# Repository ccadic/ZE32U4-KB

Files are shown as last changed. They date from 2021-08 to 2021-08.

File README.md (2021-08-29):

# ZE32U4-KB
12 low profile keys USB Keyboard with OLED, an ATMega32U4
Dr CADIC Philippe pcadic@gmail.com
GPL 3

This directory also has solidworks files for 3D files

The KAILH low profile are purchasable here: https://fr.aliexpress.com/item/32989908397.html?spm=a2g0s.9042311.0.0.27426c37iG4w2C
The Arduino like ATMEGA is a PRO MICRO : https://www.amazon.com/OSOYOO-ATmega32U4-arduino-Leonardo-ATmega328/dp/B012FOV17O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
The OLED is an I2C SSD1336: https://www.amazon.com/Pieces-Display-Module-SSD1306-3-3V-5V/dp/B08CDN5PSJ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

Size: 70x80

You have a demo software for aduino in the appropriate subdirectory.

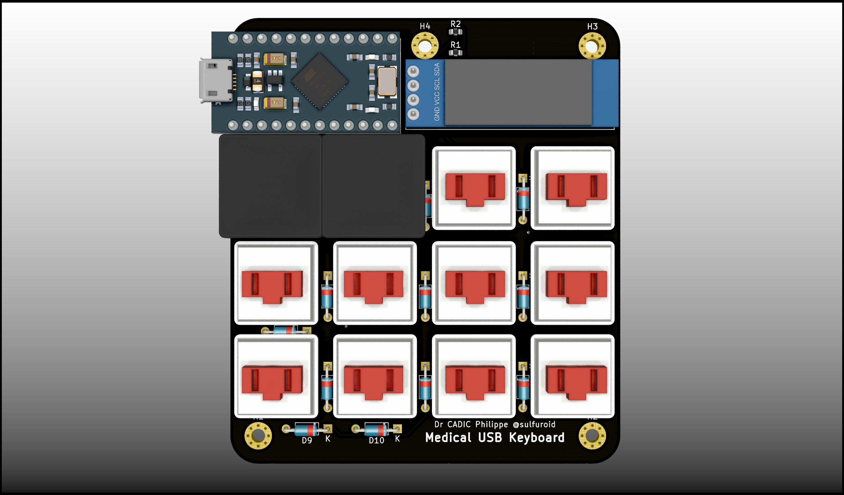
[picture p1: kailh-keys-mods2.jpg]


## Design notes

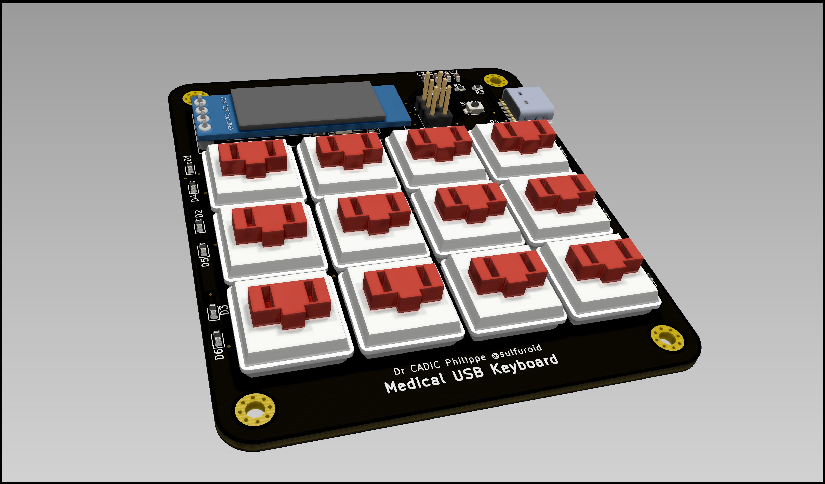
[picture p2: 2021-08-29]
kailh-keys5.jpg

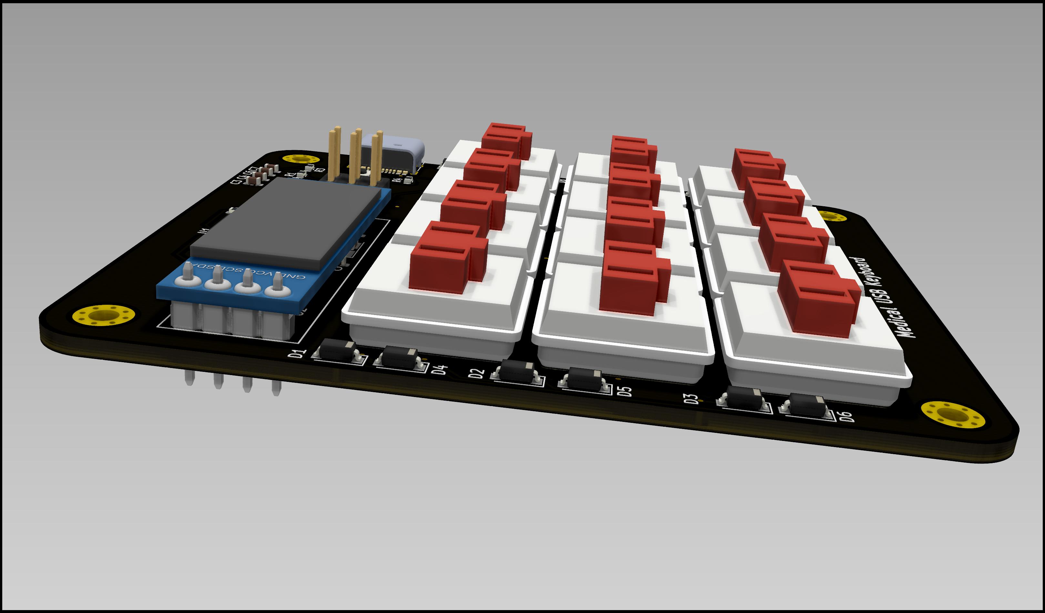
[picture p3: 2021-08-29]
kailh-keys4.jpg

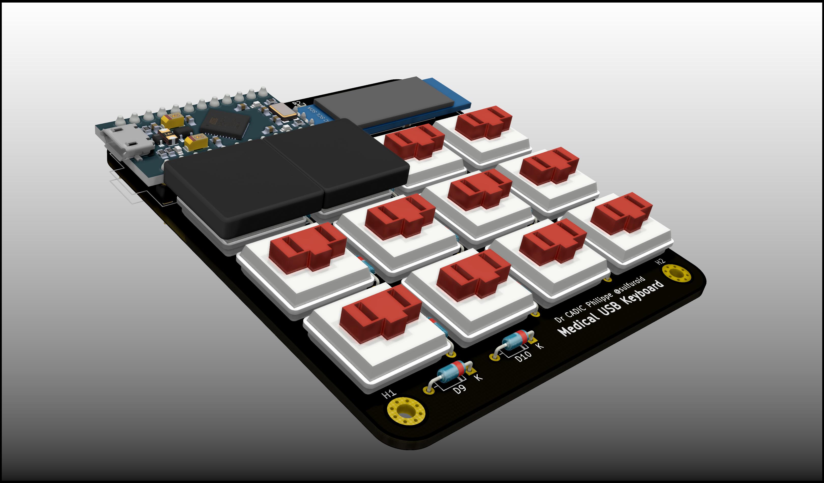
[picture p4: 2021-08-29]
kailh-keys-mods.jpg

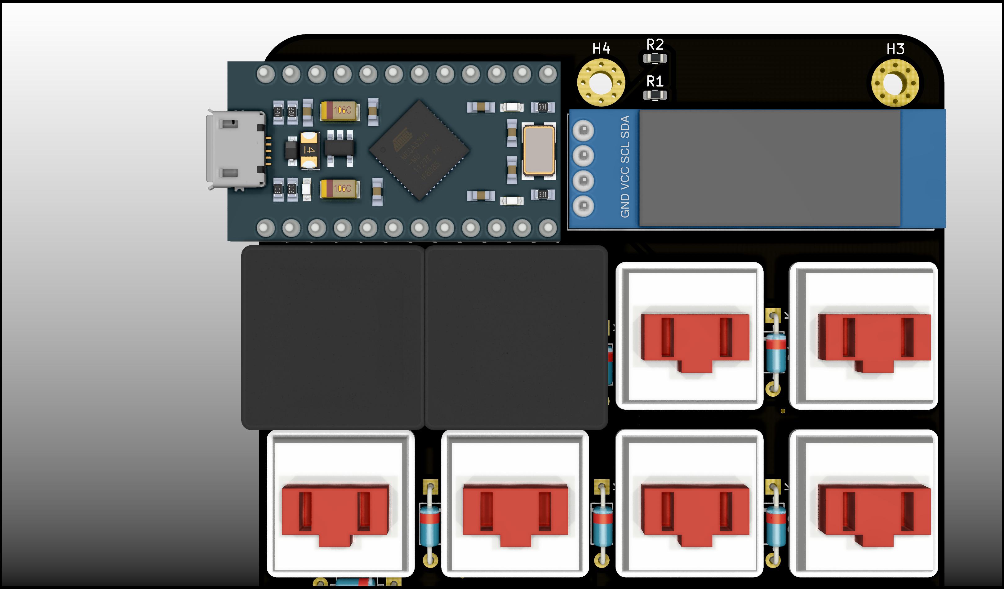
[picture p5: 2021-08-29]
kailh-keys-mods3.jpg

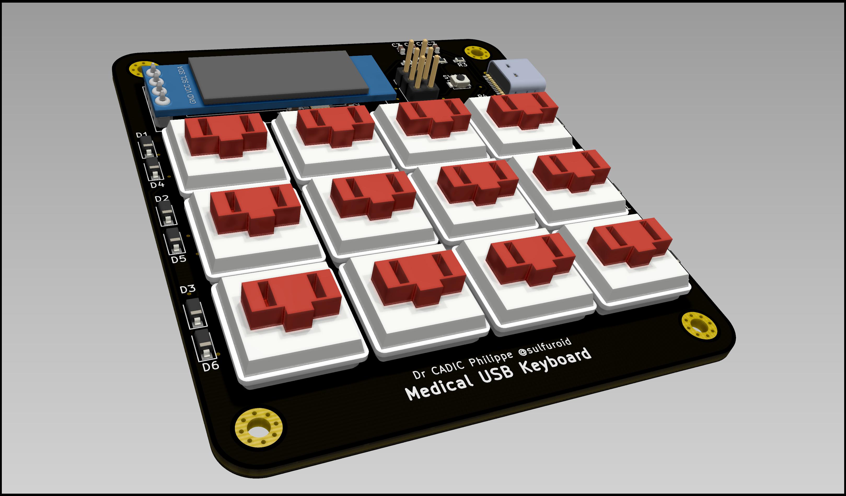
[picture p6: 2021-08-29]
kailh-keys2.jpg

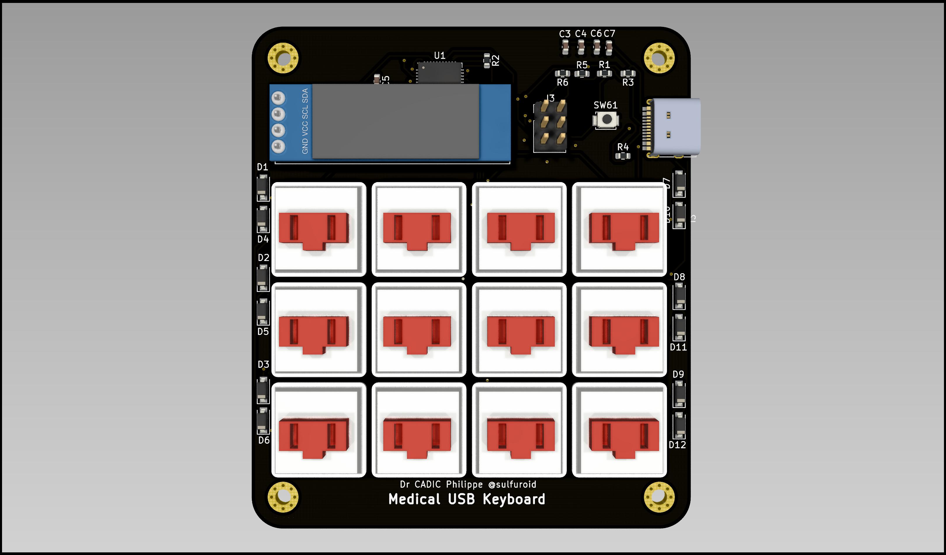
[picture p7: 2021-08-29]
kailh-keys.jpg

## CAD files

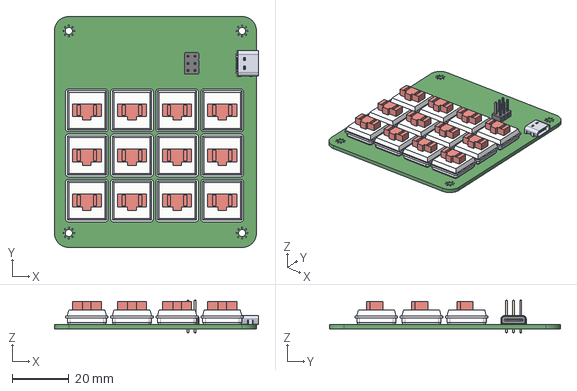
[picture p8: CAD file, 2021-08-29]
kailh-keys - 3Dprint.step
71.9 x 81.3 x 11.5 mm

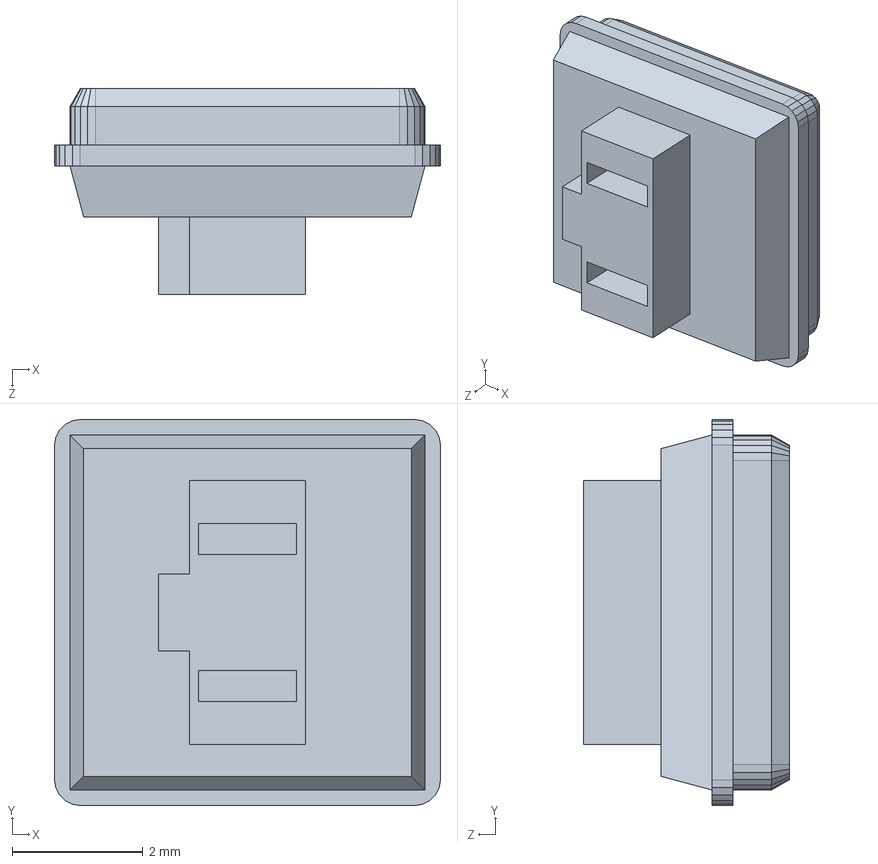
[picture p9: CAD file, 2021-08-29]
shapes3D/kailh choclp.wrl.SLDPRT
5.91 x 5.91 x 3.15 mm

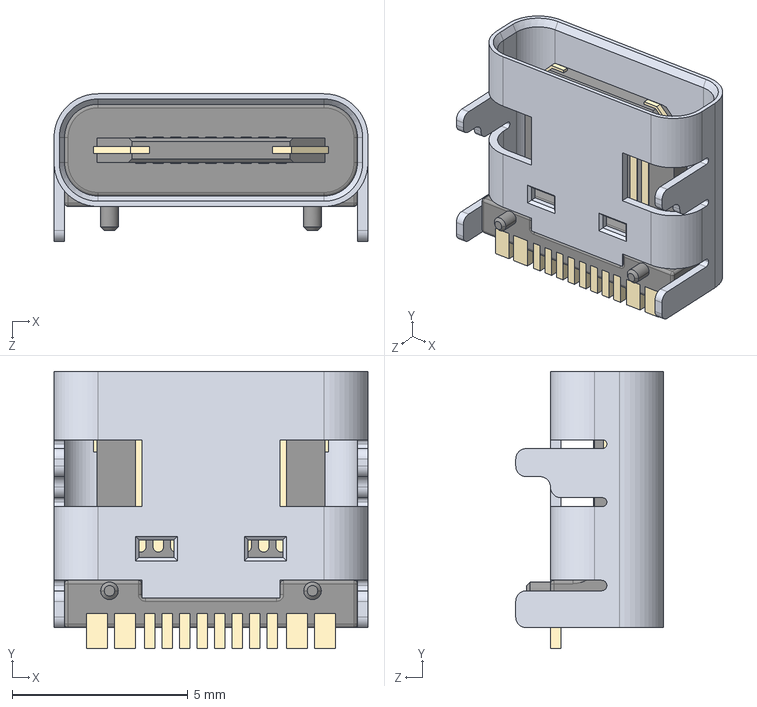
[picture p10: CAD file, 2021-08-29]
USB Type C Port (SMD Type).STEP
8.94 x 7.90 x 4.20 mm

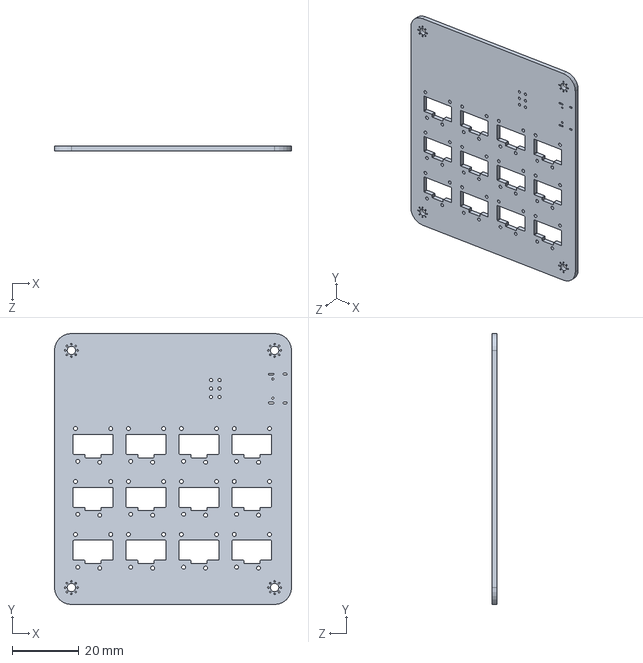
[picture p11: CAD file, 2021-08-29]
Pièce3.SLDPRT
71.1 x 81.3 x 1.60 mm

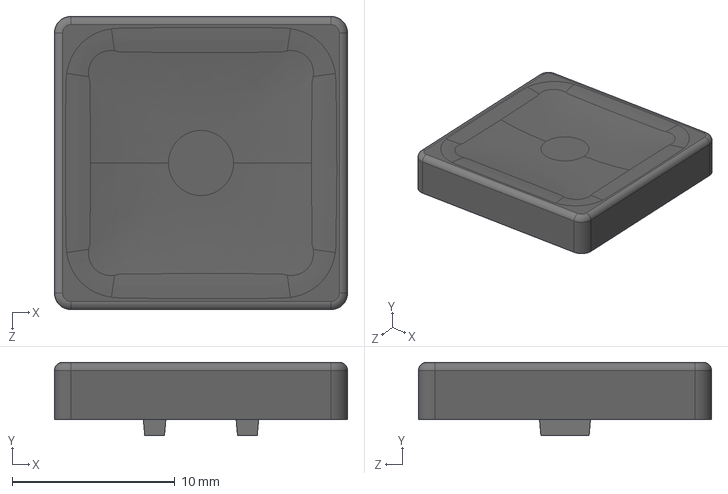
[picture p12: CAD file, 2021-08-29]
choc.STEP
18.0 x 4.50 x 18.0 mm

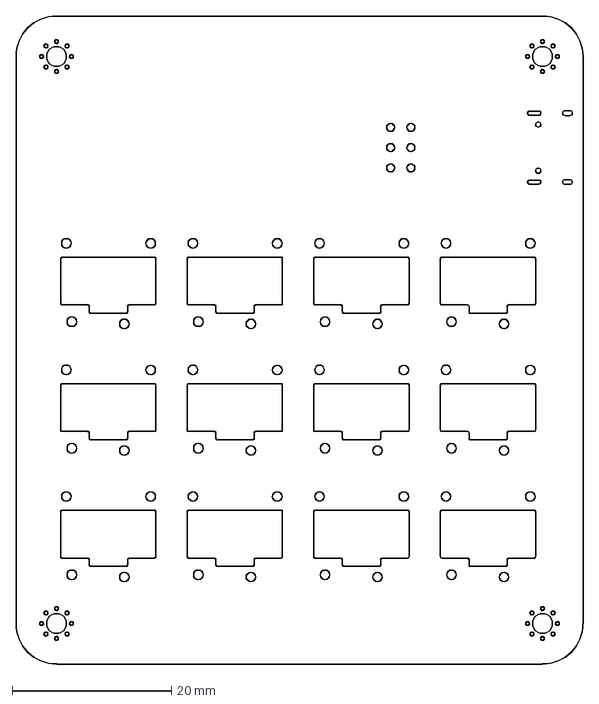
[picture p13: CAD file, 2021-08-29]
miniclavier3.DXF
71.1 x 81.3 mm

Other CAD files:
kailh-keys - 3Dprint45.step
kailh-keys - 3Dprint.STL
kailh-keys - 3Dprint45.SLDASM
kailh-keys - 3Dprint45.SLDPRT

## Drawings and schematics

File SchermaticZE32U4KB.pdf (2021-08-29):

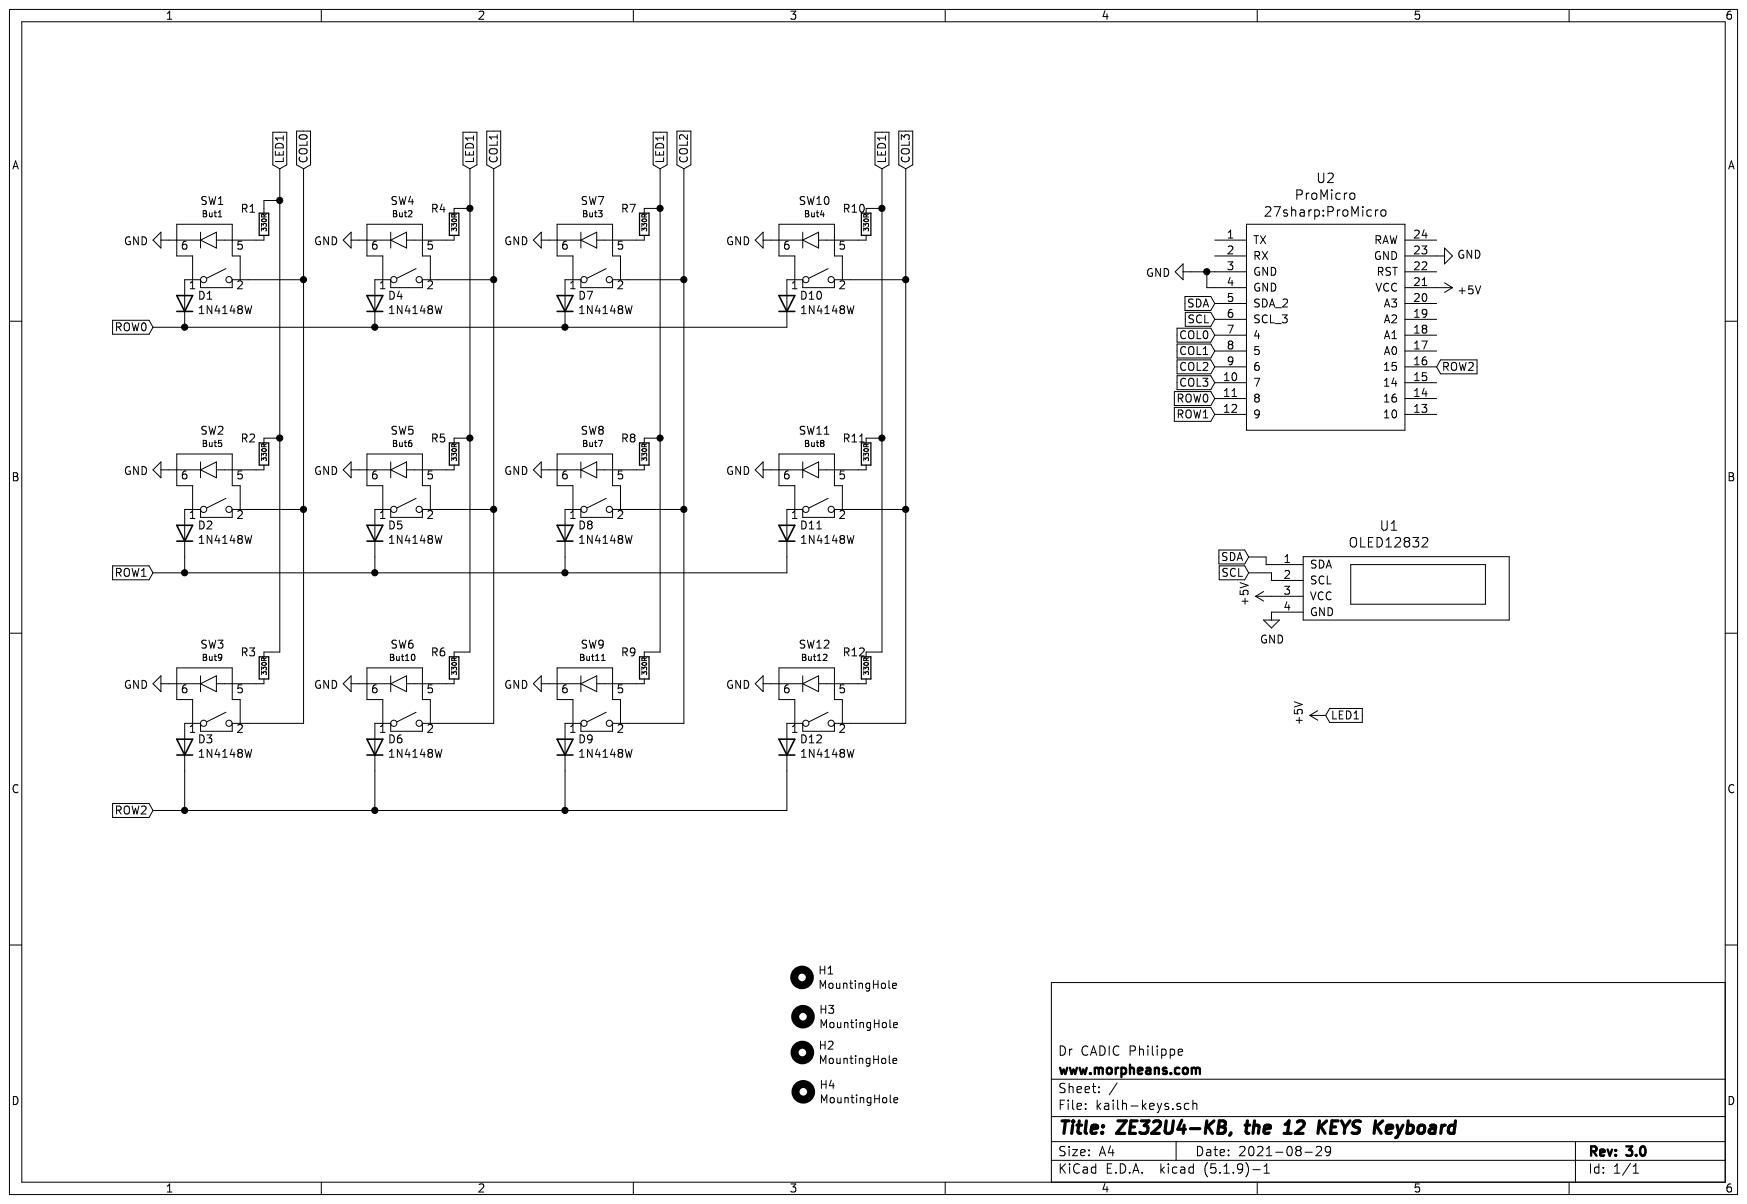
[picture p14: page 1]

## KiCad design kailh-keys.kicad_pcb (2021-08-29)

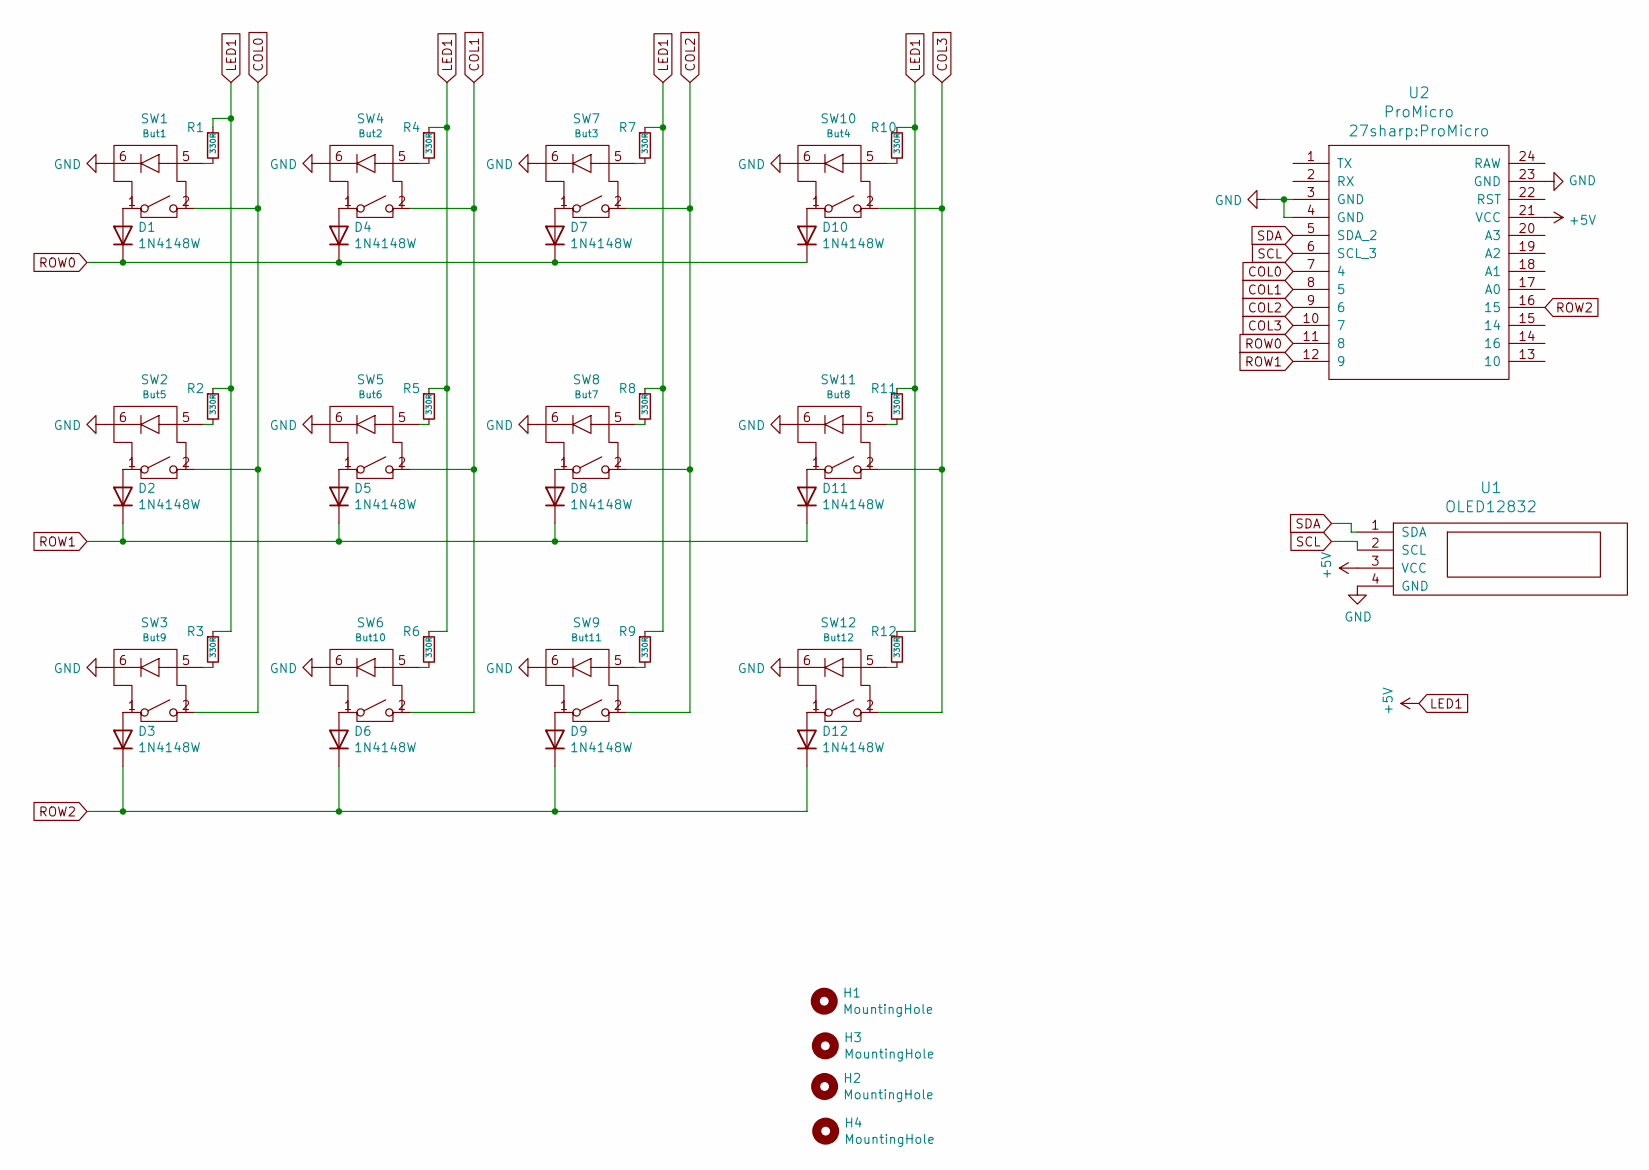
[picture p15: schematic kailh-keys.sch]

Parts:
D1, D2, D3, D4, D5, D6, D7, D8, D9, D10, D11, D12: 1N4148W; D_DO-35_SOD27_P7.62mm_Horizontal
H1, H2, H3, H4: MountingHole; MountingHole_2.5mm_Pad_Via
R1, R2, R3, R4, R5, R6, R7, R8, R9, R10, R11, R12: 330R; R_0603_1608Metric_Pad0.98x0.95mm_HandSolder
SW1: But1; KailhLP
SW2: But5; KailhLP
SW3: But9; KailhLP
SW4: But2; KailhLP
SW5: But6; KailhLP
SW6: But10; KailhLP
SW7: But3; KailhLP
SW8: But7; KailhLP
SW9: But11; KailhLP
SW10: But4; KailhLP
SW11: But8; KailhLP
SW12: But12; KailhLP
U1: OLED12832; OLED-0.91-128x32
U2: ProMicro

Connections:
COL0: SW1.2 (B), SW2.2 (B), SW3.2 (B), U2.7 (4)
COL1: SW4.2 (B), SW5.2 (B), SW6.2 (B), U2.8 (5)
COL2: SW7.2 (B), SW8.2 (B), SW9.2 (B), U2.9 (6)
COL3: SW10.2 (B), SW11.2 (B), SW12.2 (B), U2.10 (7)
GND: SW1.6 (Cath), SW2.6 (Cath), SW3.6 (Cath), SW4.6 (Cath), SW5.6 (Cath), SW6.6 (Cath), SW7.6 (Cath), SW8.6 (Cath), SW9.6 (Cath), SW10.6 (Cath), SW11.6 (Cath), SW12.6 (Cath), U1.4 (GND), U2.3 (GND), U2.4 (GND), U2.23 (GND)
LED1: R1.1, R2.1, R3.1, R4.1, R5.1, R6.1, R7.1, R8.1, R9.1, R10.1, R11.1, R12.1, U1.3 (VCC), U2.21 (VCC)
unnamed: D1.2 (A), SW1.1 (A)
unnamed: D2.2 (A), SW2.1 (A)
unnamed: D3.2 (A), SW3.1 (A)
unnamed: D4.2 (A), SW4.1 (A)
unnamed: D5.2 (A), SW5.1 (A)
unnamed: D6.2 (A), SW6.1 (A)
unnamed: D7.2 (A), SW7.1 (A)
unnamed: D8.2 (A), SW8.1 (A)
unnamed: D9.2 (A), SW9.1 (A)
unnamed: D10.2 (A), SW10.1 (A)
unnamed: D11.2 (A), SW11.1 (A)
unnamed: D12.2 (A), SW12.1 (A)
unnamed: R1.2, SW1.5 (Anod)
unnamed: R2.2, SW2.5 (Anod)
unnamed: R3.2, SW3.5 (Anod)
unnamed: R4.2, SW4.5 (Anod)
unnamed: R5.2, SW5.5 (Anod)
unnamed: R6.2, SW6.5 (Anod)
unnamed: R7.2, SW7.5 (Anod)
unnamed: R8.2, SW8.5 (Anod)
unnamed: R9.2, SW9.5 (Anod)
unnamed: R10.2, SW10.5 (Anod)
unnamed: R11.2, SW11.5 (Anod)
unnamed: R12.2, SW12.5 (Anod)
ROW0: D1.1 (K), D4.1 (K), D7.1 (K), D10.1 (K), U2.11 (8)
ROW1: D2.1 (K), D5.1 (K), D8.1 (K), D11.1 (K), U2.12 (9)
ROW2: D3.1 (K), D6.1 (K), D9.1 (K), D12.1 (K), U2.16 (15)
SCL: U1.2 (SCL), U2.6 (SCL_3)
SDA: U1.1 (SDA), U2.5 (SDA_2)

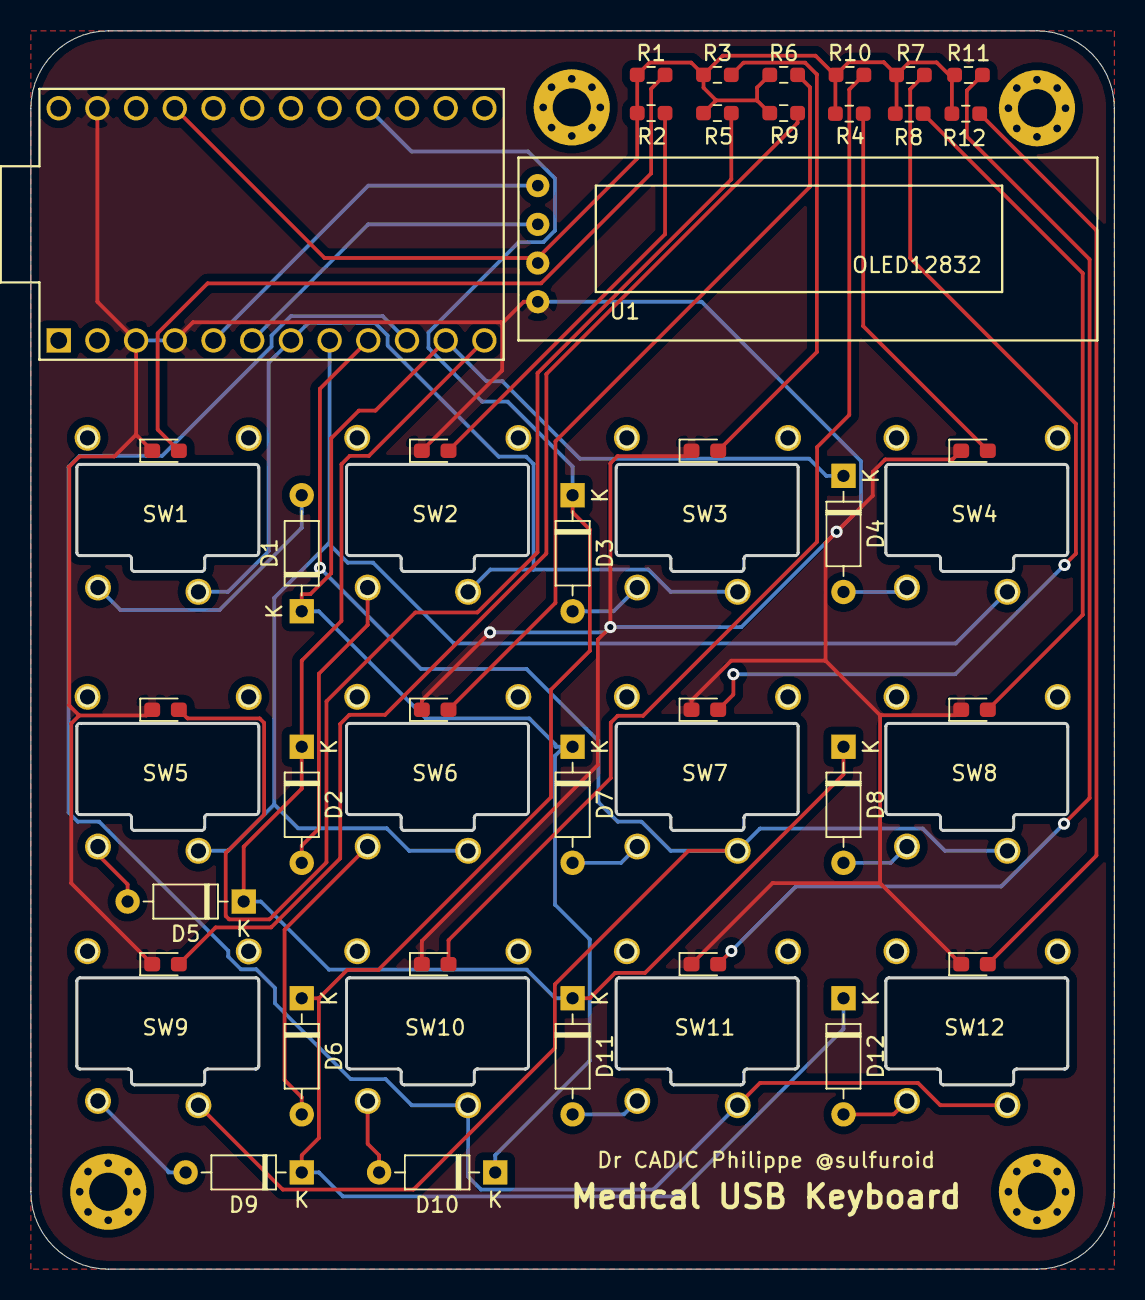
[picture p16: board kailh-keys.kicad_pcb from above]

Board: 2 copper layers, 71.1 x 81.3 mm, 42 parts (0 on the bottom side), 35 nets.

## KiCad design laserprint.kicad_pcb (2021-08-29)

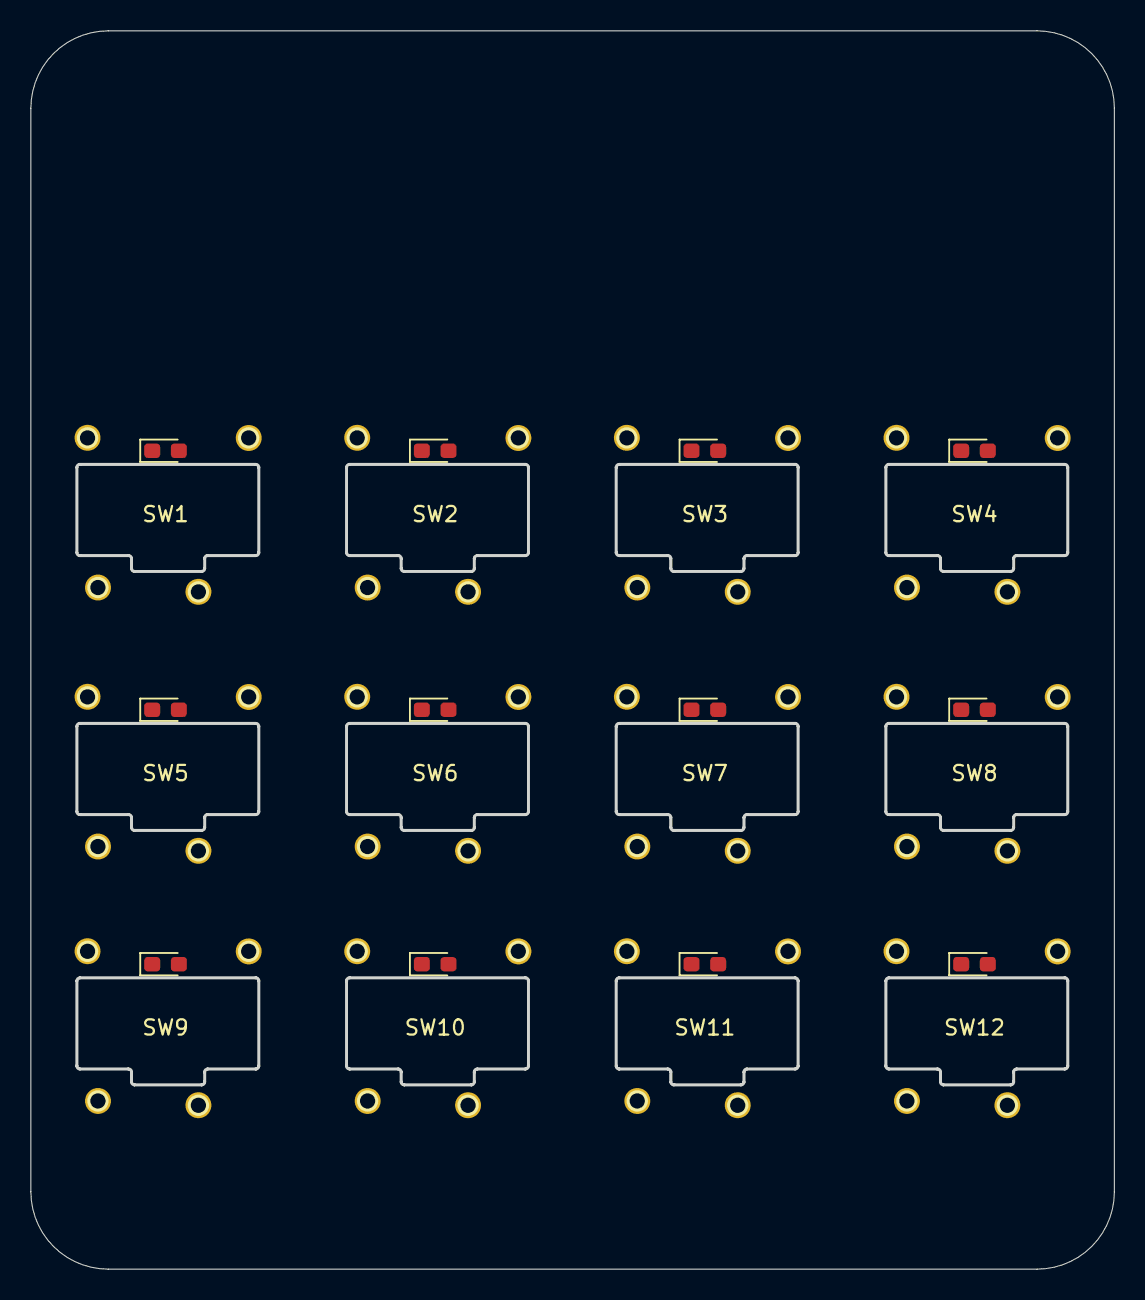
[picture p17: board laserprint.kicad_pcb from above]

Board: 2 copper layers, 71.1 x 81.3 mm, 12 parts (0 on the bottom side), 5 nets, no tracks yet.

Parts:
SW1: But1; KailhLP
SW2: But5; KailhLP
SW3: But9; KailhLP
SW4: But2; KailhLP
SW5: But6; KailhLP
SW6: But10; KailhLP
SW7: But3; KailhLP
SW8: But7; KailhLP
SW9: But11; KailhLP
SW10: But4; KailhLP
SW11: But8; KailhLP
SW12: But12; KailhLP

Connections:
COL0: SW1.2, SW2.2, SW3.2
COL1: SW4.2, SW5.2, SW6.2
COL2: SW7.2, SW8.2, SW9.2
COL3: SW10.2, SW11.2, SW12.2
GND: SW1.6, SW2.6, SW3.6, SW4.6, SW5.6, SW6.6, SW7.6, SW8.6, SW9.6, SW10.6, SW11.6, SW12.6

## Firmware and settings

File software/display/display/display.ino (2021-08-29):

// Simple I2C test for ebay 128x32 oled.

#include <Wire.h>
#include "SSD1306Ascii.h"
#include "SSD1306AsciiWire.h"

// 0X3C+SA0 - 0x3C or 0x3D
#define I2C_ADDRESS 0x3C

// Define proper RST_PIN if required.
#define RST_PIN -1

SSD1306AsciiWire oled;
//------------------------------------------------------------------------------
void setup() {
  Wire.begin();
  Wire.setClock(400000L);

#if RST_PIN >= 0
  oled.begin(&Adafruit128x32, I2C_ADDRESS, RST_PIN);
#else // RST_PIN >= 0
  oled.begin(&Adafruit128x32, I2C_ADDRESS);
#endif // RST_PIN >= 0

  oled.setFont(Adafruit5x7);

  uint32_t m = micros();
  oled.clear();
  // first row
  oled.println("Dr CADIC Philippe");

  // second row
  oled.set2X();
  oled.println("Medical KB");

  // third row
  //oled.set1X();
  //oled.print("micros: ");
  //oled.print(micros() - m);
  oled.set1X();
  oled.print("@morpheans");
  
  
}
//------------------------------------------------------------------------------
void loop() {}

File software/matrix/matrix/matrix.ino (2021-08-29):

// Keyboard Matrix Tutorial Example
// baldengineer.com
// CC BY-SA 4.0
  
// JP1 is an input
byte rows[] = {8,9,15};
const int rowCount = sizeof(rows)/sizeof(rows[0]);
 
// JP2 and JP3 are outputs
byte cols[] = {4,5,6,7};
const int colCount = sizeof(cols)/sizeof(cols[0]);
 
byte keys[colCount][rowCount];
 
void setup() {
    Serial.begin(115200);
 
    for(int x=0; x<rowCount; x++) {
        Serial.print(rows[x]); Serial.println(" as input");
        pinMode(rows[x], INPUT);
    }
 
    for (int x=0; x<colCount; x++) {
        Serial.print(cols[x]); Serial.println(" as input-pullup");
        pinMode(cols[x], INPUT_PULLUP);
    }
         
}
 
void readMatrix() {
    // iterate the columns
    for (int colIndex=0; colIndex < colCount; colIndex++) {
        // col: set to output to low
        byte curCol = cols[colIndex];
        pinMode(curCol, OUTPUT);
        digitalWrite(curCol, LOW);
 
        // row: interate through the rows
        for (int rowIndex=0; rowIndex < rowCount; rowIndex++) {
            byte rowCol = rows[rowIndex];
            pinMode(rowCol, INPUT_PULLUP);
            keys[colIndex][rowIndex] = digitalRead(rowCol);
            pinMode(rowCol, INPUT);
        }
        // disable the column
        pinMode(curCol, INPUT);
    }
}
 
void printMatrix() {
    for (int rowIndex=0; rowIndex < rowCount; rowIndex++) {
        if (rowIndex < 10)
            Serial.print(F("0"));
        Serial.print(rowIndex); Serial.print(F(": "));
 
        for (int colIndex=0; colIndex < colCount; colIndex++) {  
            Serial.print(keys[colIndex][rowIndex]);
            if (colIndex < colCount)
                Serial.print(F(", "));
        }   
        Serial.println("");
    }
    Serial.println("");
}
 
void loop() {
    readMatrix();
    if (Serial.read()=='!')
        printMatrix();
}
